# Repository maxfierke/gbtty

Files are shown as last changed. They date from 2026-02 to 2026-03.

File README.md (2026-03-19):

# gbtty

gbtty (pronounced: _gib-bit-EE_ / "gibbity") is a Game Boy (Color) hardware and
software project to turn the Game Boy into an ANSI-compatible terminal.

# Goals

The primary goal of this project is _funsies_. I wanted to work on a side
project where I could use Rust, play around with an RP2040, and do something
related to my current hyperfixation: the Game Boy.

Secondary goals include providing a useful-enough implementation of an ANSI
terminal, at least to be VT100-compatible to the extent that matters for modern
purposes.

Some stretch goals include supporting a broad set of ANSI escape codes, such as
text/background color on the Game Boy Color, some support for scrollback, and
perhaps even some support for some TUI elements depending on how wild I decide
to get with this.

## Anti-goals

I am not planning on turning this into an interactive terminal accepting input
to be passed back to the host. The only possible way to make this work would be
using some sort of on-screen keyboard control, and I am simply not masochistic
enough to use that.

# Current status

The software side of things is _mostly_ working for basic printing and support
for cursor movement, cursor reporting, and a few other CSI sequences. It's
currently setup to compile and run on the Waveshare RP2040-Zero and configured
to run on [this pico-gb-printer board](https://github.com/Raphael-Boichot/Collection-of-PCB-for-Game-Boy-Printer-Emulators/tree/main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)
as I happened to have a couple of these, but should be configurable to run on
other similar boards by remapping the GPIOs & swapping the BSP crate.

The hardware is still a work in-progress. The `pcb/` has a few different v1.0
designs that still need to be tested. The design is more-or-less the same as
other USB-to-link-cable boards out there, but I'm eventually trying to get it as
close as I can to the footprint of a USB-to-UART adapter.

# License

The firmware of the link adapter (contents of the root & `src/` directory) is
licensed under either the [Apache License Version 2.0](LICENSE-APACHE-2-0) or
[The MIT License](LICENSE-MIT)

The PCB (contents of `pcb/`) is licensed under
[Creative Commons Attribution-NonCommercial-ShareAlike 4.0 International](https://creativecommons.org/licenses/by-nc-sa/4.0/). **Commercial uses are strictly prohibited.**

The terminal emulator ROM itself (contents of the `gb/` directory) is derived
from orangeglo's Better Button Test, which is licensed under the [GNU General
Public License Version 3](gb/LICENSE), so the same license applies.

# Disclaimer

Game Boy™ is a trademark of Nintendo of America Inc.

# Useful resources

- [How Terminals Work](https://how-terminals-work.vercel.app/) - Interactive look at how ANSI terminals function (VT100 and xterm derivatives especially)
- [vt100.net/emu/](https://vt100.net/emu/) - Paul Flo Williams' tome on terminal emulation
- [Everything you never wanted to know about ANSI escape codes](https://notes.burke.libbey.me/ansi-escape-codes/)

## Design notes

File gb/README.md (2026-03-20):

# gbtty - GB client

This is the GB client application which actually runs on the Game Boy and does
the emulating of the VT100 by interpretting input delivered over the link port.

It's primarily a consumer, but does support some limited responses back to the
host, including cursor reporting, device attributes, as well as ACK and SYN IDLE.

## License

As mentioned in the [top-level README](../README.md) for the project, the GB client is licensed
under the terms of the GNU General Public License Version 3.

It uses elements of other projects licensed under the GNU General Public License
Version 3 or compatible licenses, including:

- [Better Button Test](https://github.com/orangeglo/better-button-test) by orangelo - original foundation of `src/main.c`, `src/palettes.h`
- [Portfolio 6x8](https://int10h.org/oldschool-pc-fonts/fontlist/font?portfolio_6x8) - bitmap font, based on FON version from [VileR](https://int10h.org/oldschool-pc-fonts/). Originally licensed under CC-BY-SA 4.0. I converted it to 8x8 1bpp tiles, which are a derivative work licensed under GNU General Public License Version 3.

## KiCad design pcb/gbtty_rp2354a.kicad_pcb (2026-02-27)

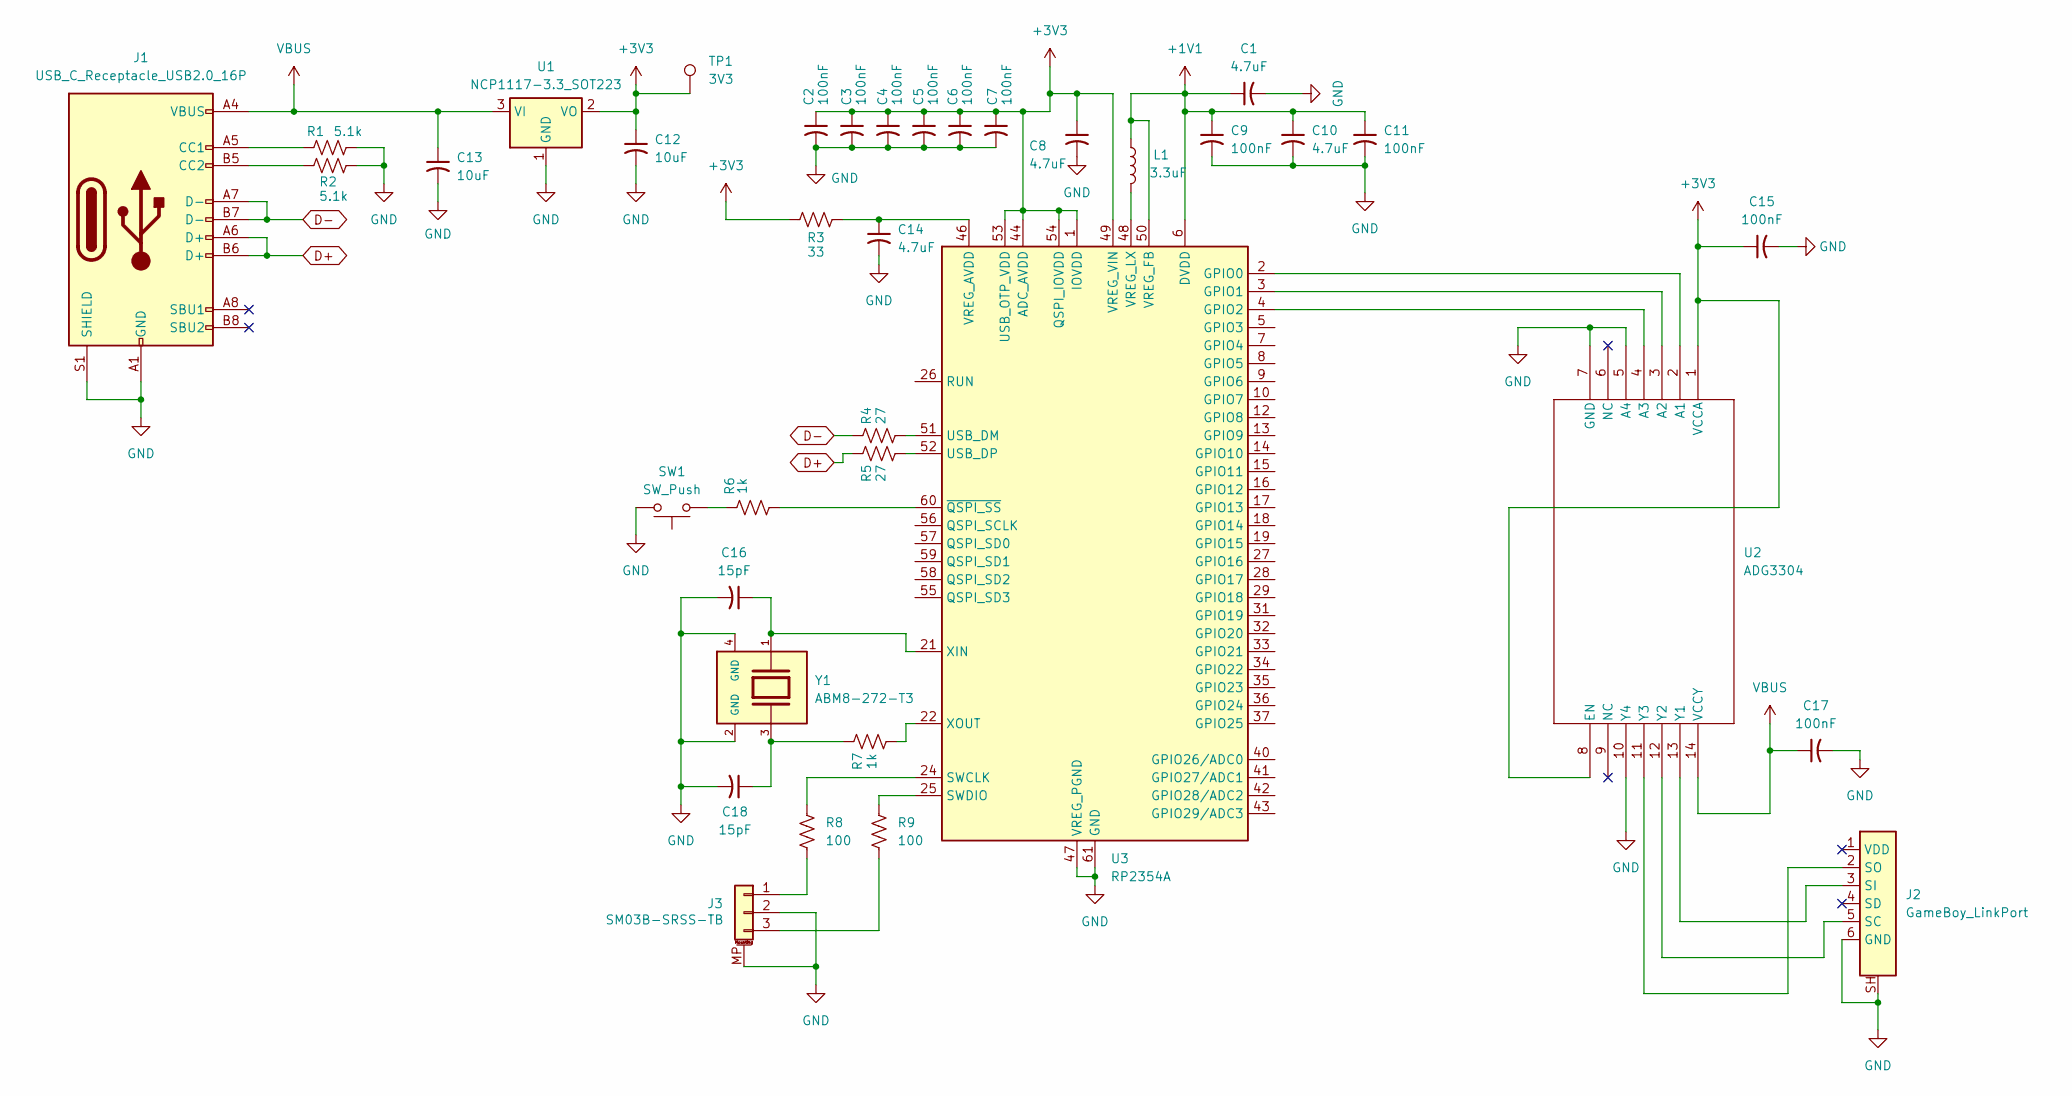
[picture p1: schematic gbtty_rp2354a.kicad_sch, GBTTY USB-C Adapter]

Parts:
C1, C8, C10, C14: 4.7uF; C_0603_1608Metric_Pad1.08x0.95mm_HandSolder
C2, C3, C4, C5, C6, C7, C9, C11, C15, C17: 100nF; C_0603_1608Metric_Pad1.08x0.95mm_HandSolder
C12, C13: 10uF; C_0603_1608Metric_Pad1.08x0.95mm_HandSolder
C16, C18: 15pF; C_0603_1608Metric_Pad1.08x0.95mm_HandSolder
J1: USB_C_Receptacle_USB2.0_16P; USB_C_Receptacle_GCT_USB4105-xx-A_16P_TopMnt_Horizontal
J2: GameBoy_LinkPort; GameBoy_LinkPort_MGB_Horizontal
J3: SM03B-SRSS-TB; JST_SH_BM03B-SRSS-TB_1x03-1MP_P1.00mm_Vertical
L1: 3.3uF; L_pol_2016
R1, R2: 5.1k; R_0603_1608Metric_Pad0.98x0.95mm_HandSolder
R3: 33; R_0603_1608Metric_Pad0.98x0.95mm_HandSolder
R4, R5: 27; R_0603_1608Metric_Pad0.98x0.95mm_HandSolder
R6, R7: 1k; R_0603_1608Metric_Pad0.98x0.95mm_HandSolder
R8, R9: 100; R_0603_1608Metric_Pad0.98x0.95mm_HandSolder
SW1: SW_Push; SW_SPST_TL3305A
TP1: 3V3; TestPoint_Pad_D1.0mm
U1: NCP1117-3.3_SOT223; SOT-223-3_TabPin2
U2: ADG3304; RU_14_ADI
U3: RP2354A; QFN-60-1EP_7x7mm_P0.4mm_EP3.4x3.4mm
Y1: ABM8-272-T3; XTAL_ABM8-272-T3; PARTREV 07-29-20

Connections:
+1V1: C1.1, C9.1, C10.1, C11.1, L1.1, U3.6 (DVDD), U3.23 (DVDD), U3.39 (DVDD), U3.50 (VREG_FB)
+3V3: C2.1, C3.1, C4.1, C5.1, C6.1, C7.1, C8.1, C12.1, C15.1, R3.2, TP1.1, U1.2 (VO), U2.1 (VCCA), U2.8 (EN), U3.1 (IOVDD), U3.11 (IOVDD), U3.20 (IOVDD), U3.30 (IOVDD), U3.38 (IOVDD), U3.44 (ADC_AVDD), U3.45 (IOVDD), U3.49 (VREG_VIN), U3.53 (USB_OTP_VDD), U3.54 (QSPI_IOVDD)
D+: J1.A6 (D+), J1.B6 (D+), R5.1
D-: J1.A7 (D-), J1.B7 (D-), R4.1
GND: C1.2, C2.2, C3.2, C4.2, C5.2, C6.2, C7.2, C8.2, C9.2, C10.2, C11.2, C12.2, C13.2, C14.2, C15.2, C16.2, C17.2, C18.2, J1.A1 (GND), J1.A12 (GND), J1.B1 (GND), J1.B12 (GND), J1.S1 (SHIELD), J2.6 (GND), J2.SH, J3.2, J3.MP (MountPin), R1.2, R2.2, SW1.2, U1.1 (GND), U2.5 (A4), U2.7 (GND), U2.10 (Y4), U3.47 (VREG_PGND), U3.61 (GND), Y1.2 (GND), Y1.4 (GND)
unnamed: C18.1, R7.1, Y1.3
unnamed: J1.A5 (CC1), R1.1
unnamed: J1.B5 (CC2), R2.1
unnamed: J2.5 (SC), U2.12 (Y2)
unnamed: J2.3 (SI), U2.13 (Y1)
unnamed: J2.2 (SO), U2.11 (Y3)
unnamed: J3.1, R8.2
unnamed: J3.3, R9.2
unnamed: R6.1, SW1.1
unnamed: U2.2 (A1), U3.2 (GPIO0)
unnamed: U2.3 (A2), U3.3 (GPIO1)
unnamed: U2.4 (A3), U3.4 (GPIO2)
unnamed: R8.1, U3.24 (SWCLK)
unnamed: R9.1, U3.25 (SWDIO)
unnamed: R4.2, U3.51 (USB_DM)
unnamed: R5.2, U3.52 (USB_DP)
unnamed: C14.1, R3.1, U3.46 (VREG_AVDD)
unnamed: L1.2, U3.48 (VREG_LX)
unnamed: C16.1, U3.21 (XIN), Y1.1
unnamed: R7.2, U3.22 (XOUT)
unnamed: R6.2, U3.60 (~QSPI_SS)
VBUS: C13.1, C17.1, J1.A4 (VBUS), J1.A9 (VBUS), J1.B4 (VBUS), J1.B9 (VBUS), U1.3 (VI), U2.14 (VCCY)

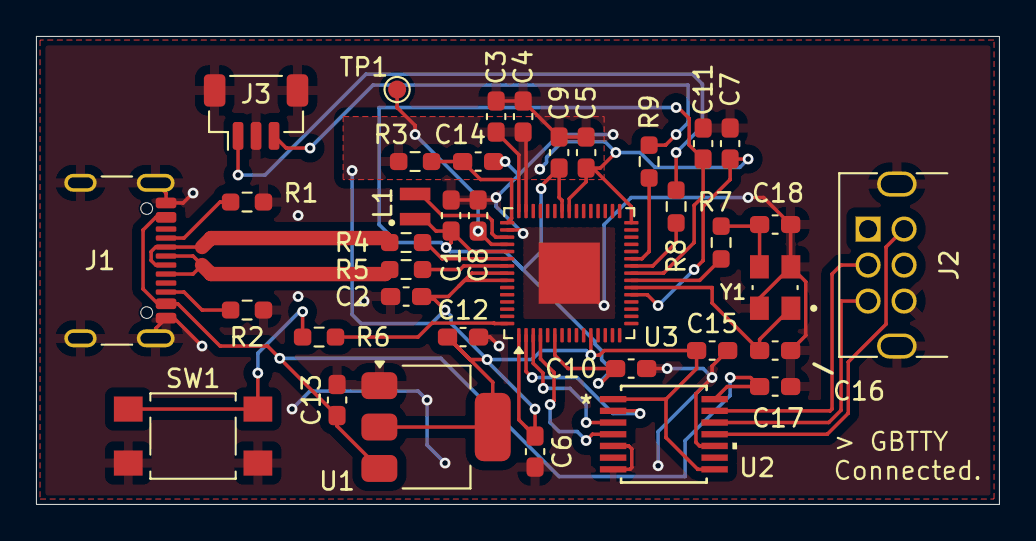
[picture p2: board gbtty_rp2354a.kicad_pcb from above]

Board: 2 copper layers, 53.5 x 26.0 mm, 37 parts (0 on the bottom side), 27 nets.

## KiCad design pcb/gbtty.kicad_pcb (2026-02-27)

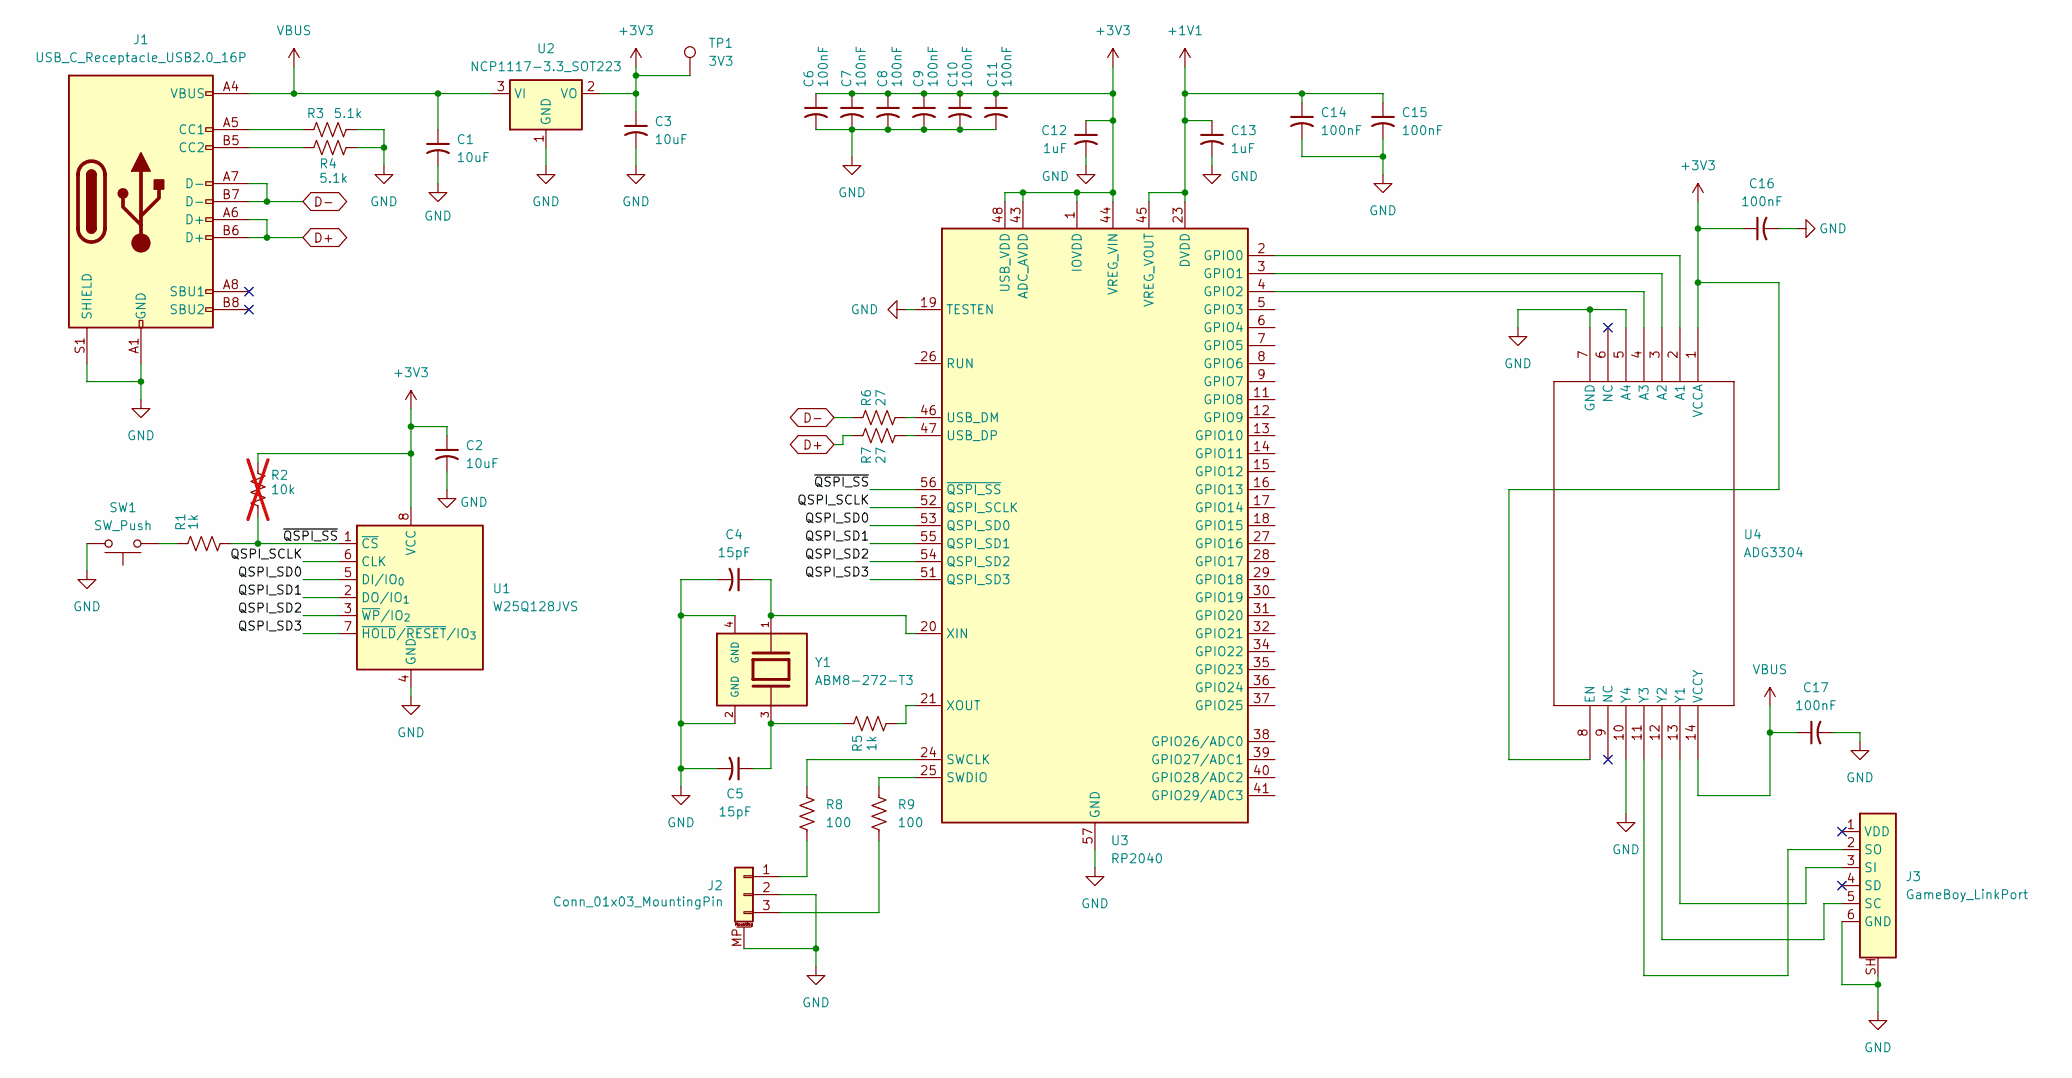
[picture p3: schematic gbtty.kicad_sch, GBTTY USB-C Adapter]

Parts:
C1, C2, C3: 10uF; C_0603_1608Metric_Pad1.08x0.95mm_HandSolder
C4, C5: 15pF; C_0603_1608Metric_Pad1.08x0.95mm_HandSolder
C6, C7, C8, C9, C10, C11, C14, C15, C16, C17: 100nF; C_0603_1608Metric_Pad1.08x0.95mm_HandSolder
C12, C13: 1uF; C_0603_1608Metric_Pad1.08x0.95mm_HandSolder
J1: USB_C_Receptacle_USB2.0_16P; USB_C_Receptacle_GCT_USB4105-xx-A_16P_TopMnt_Horizontal
J2: Conn_01x03_MountingPin; JST_SH_BM03B-SRSS-TB_1x03-1MP_P1.00mm_Vertical
J3: GameBoy_LinkPort; GameBoy_LinkPort_MGB_Horizontal
R1, R5: 1k; R_0603_1608Metric_Pad0.98x0.95mm_HandSolder
R2: 10k; R_0603_1608Metric_Pad0.98x0.95mm_HandSolder; not fitted
R3, R4: 5.1k; R_0603_1608Metric_Pad0.98x0.95mm_HandSolder
R6, R7: 27; R_0603_1608Metric_Pad0.98x0.95mm_HandSolder
R8, R9: 100; R_0603_1608Metric_Pad0.98x0.95mm_HandSolder
SW1: SW_Push; SW_SPST_TL3305A
TP1: 3V3; TestPoint_Pad_D1.0mm
U1: W25Q128JVS; SOIC-8_5.3x5.3mm_P1.27mm
U2: NCP1117-3.3_SOT223; SOT-223-3_TabPin2
U3: RP2040; QFN-56-1EP_7x7mm_P0.4mm_EP3.2x3.2mm
U4: ADG3304; RU_14_ADI
Y1: ABM8-272-T3; XTAL_ABM8-272-T3; PARTREV 07-29-20

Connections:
+1V1: C13.1, C14.1, C15.1, U3.23 (DVDD), U3.45 (VREG_VOUT), U3.50 (DVDD)
+3V3: C2.1, C3.1, C6.1, C7.1, C8.1, C9.1, C10.1, C11.1, C12.1, C16.1, R2.1, TP1.1, U1.8 (VCC), U2.2 (VO), U3.1 (IOVDD), U3.10 (IOVDD), U3.22 (IOVDD), U3.33 (IOVDD), U3.42 (IOVDD), U3.43 (ADC_AVDD), U3.44 (VREG_VIN), U3.48 (USB_VDD), U3.49 (IOVDD), U4.1 (VCCA), U4.8 (EN)
/QSPI_SCLK: U1.6 (CLK), U3.52 (QSPI_SCLK)
/QSPI_SD0: U1.5 (DI/IO_{0}), U3.53 (QSPI_SD0)
/QSPI_SD1: U1.2 (DO/IO_{1}), U3.55 (QSPI_SD1)
/QSPI_SD2: U1.3 (~WP/IO_{2}), U3.54 (QSPI_SD2)
/QSPI_SD3: U1.7 (~HOLD/~RESET/IO_{3}), U3.51 (QSPI_SD3)
/~QSPI_SS: R1.2, R2.2, U1.1 (~CS), U3.56 (~QSPI_SS)
D+: J1.A6 (D+), J1.B6 (D+), R7.1
D-: J1.A7 (D-), J1.B7 (D-), R6.1
GND: C1.2, C2.2, C3.2, C4.2, C5.2, C6.2, C7.2, C8.2, C9.2, C10.2, C11.2, C12.2, C13.2, C14.2, C15.2, C16.2, C17.2, J1.A1 (GND), J1.A12 (GND), J1.B1 (GND), J1.B12 (GND), J1.S1 (SHIELD), J2.2, J2.MP (MountPin), J3.6 (GND), J3.SH, R3.2, R4.2, SW1.2, U1.4 (GND), U2.1 (GND), U3.19 (TESTEN), U3.57 (GND), U4.5 (A4), U4.7 (GND), U4.10 (Y4), Y1.2 (GND), Y1.4 (GND)
unnamed: C5.1, R5.1, Y1.3
unnamed: J1.A5 (CC1), R3.1
unnamed: J1.B5 (CC2), R4.1
unnamed: J2.1, R8.2
unnamed: J2.3, R9.2
unnamed: J3.5 (SC), U4.12 (Y2)
unnamed: J3.3 (SI), U4.13 (Y1)
unnamed: J3.2 (SO), U4.11 (Y3)
unnamed: R1.1, SW1.1
unnamed: U3.2 (GPIO0), U4.2 (A1)
unnamed: U3.3 (GPIO1), U4.3 (A2)
unnamed: U3.4 (GPIO2), U4.4 (A3)
unnamed: R8.1, U3.24 (SWCLK)
unnamed: R9.1, U3.25 (SWDIO)
unnamed: R6.2, U3.46 (USB_DM)
unnamed: R7.2, U3.47 (USB_DP)
unnamed: C4.1, U3.20 (XIN), Y1.1
unnamed: R5.2, U3.21 (XOUT)
VBUS: C1.1, C17.1, J1.A4 (VBUS), J1.A9 (VBUS), J1.B4 (VBUS), J1.B9 (VBUS), U2.3 (VI), U4.14 (VCCY)

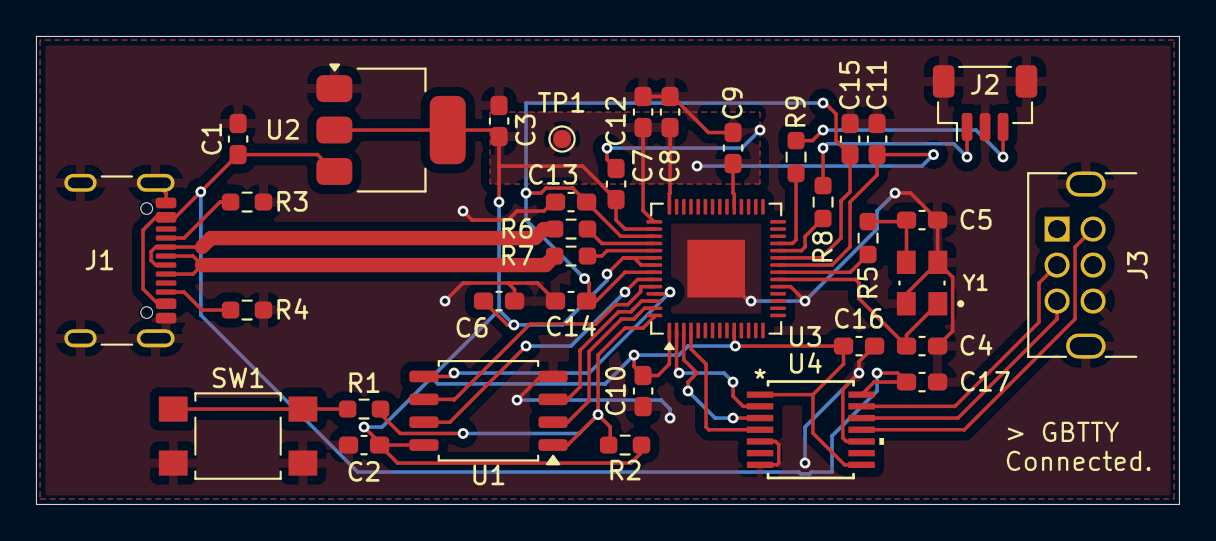
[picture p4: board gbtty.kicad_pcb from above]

Board: 2 copper layers, 63.5 x 26.0 mm, 36 parts (0 on the bottom side), 30 nets.

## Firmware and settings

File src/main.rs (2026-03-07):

//! Runs a Serial TTY to GB link translation
//!
//! This allows a GB to act as an ANSI terminal (assuming software support on
//! the GB side)
#![no_std]
#![no_main]
#![allow(static_mut_refs)]

use bsp::entry;
use defmt::*;
use defmt_rtt as _;
use rp2040_panic_usb_boot as _;

use heapless::spsc::{Producer, Queue};
use usb_device::{
    bus::UsbBusAllocator,
    device::{StringDescriptors, UsbDevice, UsbDeviceBuilder, UsbVidPid},
};
use usbd_serial::{
    embedded_io::{Read, Write},
    SerialPort,
};

#[cfg(feature = "rp-pico")]
pub use rp_pico as bsp;

#[cfg(feature = "waveshare-rp2040-zero")]
pub use waveshare_rp2040_zero as bsp;

use bsp::hal::{
    clocks::{init_clocks_and_plls, Clock},
    fugit,
    gpio::{FunctionPio0, Pin},
    pac::{self, interrupt, Interrupt},
    pio,
    sio::Sio,
    usb::UsbBus,
    watchdog::Watchdog,
};

mod link_port;

/// The USB Device Driver (shared with the interrupt).
static mut USB_DEVICE: Option<UsbDevice<bsp::hal::usb::UsbBus>> = None;

/// The USB Bus Driver (shared with the interrupt).
static mut USB_BUS: Option<UsbBusAllocator<bsp::hal::usb::UsbBus>> = None;

/// The USB Serial Device Driver (shared with the interrupt).
static mut USB_SERIAL: Option<SerialPort<bsp::hal::usb::UsbBus>> = None;

/// Link port TX queue writer
static mut LINK_PORT_BUFFER_WRITER: Option<Producer<'_, u8>> = None;

const LINK_PORT_CLOCK_HZ: u32 = 262144; // ~32KB/s on normal speed

const LINK_PORT_ACK: u8 = 0x6;

const LINK_PORT_SYN_IDLE: u8 = 0x16;

#[entry]
fn main() -> ! {
    let mut pac = pac::Peripherals::take().unwrap();
    let mut watchdog = Watchdog::new(pac.WATCHDOG);
    let sio = Sio::new(pac.SIO);

    let clocks = init_clocks_and_plls(
        bsp::XOSC_CRYSTAL_FREQ,
        pac.XOSC,
        pac.CLOCKS,
        pac.PLL_SYS,
        pac.PLL_USB,
        &mut pac.RESETS,
        &mut watchdog,
    )
    .ok()
    .unwrap();

    let clock_cycles_per_ms = clocks.system_clock.freq().to_Hz() / 1000;

    let pins = bsp::Pins::new(
        pac.IO_BANK0,
        pac.PADS_BANK0,
        sio.gpio_bank0,
        &mut pac.RESETS,
    );

    #[cfg(feature = "rp-pico")]
    let (sin_pin, sck_pin, sout_pin) = {
        let gp0: Pin<_, FunctionPio0, _> = pins.gp0.into_function();
        let gp1: Pin<_, FunctionPio0, _> = pins.gp1.into_function();
        let gp2: Pin<_, FunctionPio0, _> = pins.gp2.into_function();
        (gp0, gp1, gp2)
    };

    #[cfg(feature = "waveshare-rp2040-zero")]
    let (sin_pin, sck_pin, sout_pin) = {
        let gp0: Pin<_, FunctionPio0, _> = pins.gp0.into_function();
        let gp2: Pin<_, FunctionPio0, _> = pins.gp2.into_function();
        let gp3: Pin<_, FunctionPio0, _> = pins.gp3.into_function();
        (gp0, gp2, gp3)
    };

    let (mut pio0, sm0, _sm1, _sm2, _sm3) = pio::PIOExt::split(pac.PIO0, &mut pac.RESETS);
    let mut leader_program = link_port::install_link_port_leader_program(&mut pio0)
        .ok()
        .unwrap();

    let port = link_port::PioGbLinkPortLeader::new(
        sin_pin.reconfigure(),
        sck_pin.reconfigure(),
        sout_pin.reconfigure(),
        sm0,
        &mut leader_program,
        fugit::HertzU32::Hz(LINK_PORT_CLOCK_HZ).convert(),
        clocks.system_clock.freq(),
    );

    let usb_bus = UsbBusAllocator::new(UsbBus::new(
        pac.USBCTRL_REGS,
        pac.USBCTRL_DPRAM,
        clocks.usb_clock,
        true,
        &mut pac.RESETS,
    ));
    unsafe {
        // SAFETY: This is safe as interrupts haven't been started yet
        USB_BUS = Some(usb_bus);
    }

    // Grab a reference to the USB Bus allocator. We are promising to the
    // compiler not to take mutable access to this global variable whilst this
    // reference exists!
    let bus_ref = unsafe { USB_BUS.as_ref().unwrap() };

    let serial = SerialPort::new(bus_ref);
    unsafe {
        USB_SERIAL = Some(serial);
    }

    let mut usb_dev = UsbDeviceBuilder::new(bus_ref, UsbVidPid(0x2E8A, 0x000A))
        .strings(&[StringDescriptors::default()
            .manufacturer("GBTTY")
            .product("Serial port that outputs to Game Boy link port")
            .serial_number("TEST")])
        .unwrap()
        .device_class(2) // from: https://www.usb.org/defined-class-codes
        .build();
    let _ = usb_dev.force_reset();
    unsafe {
        // SAFETY: This is safe as interrupts haven't been started yet
        USB_DEVICE = Some(usb_dev);
    }

    let mut link_port_queue_reader = {
        let (p, c) = {
            static mut LINK_PORT_BUFFER_QUEUE: Queue<u8, 4096> = Queue::new();
            // SAFETY: `LINK_PORT_BUFFER_QUEUE` is only accessible in this scope
            // and `main` is only called once.
            #[allow(static_mut_refs)]
            unsafe {
                LINK_PORT_BUFFER_QUEUE.split()
            }
        };

        unsafe {
            LINK_PORT_BUFFER_WRITER = Some(p);
        };

        c
    };

    // Enable the USB interrupt
    unsafe {
        pac::NVIC::unmask(Interrupt::USBCTRL_IRQ);
    };

    let mut active_link_port = port.enable();

    loop {
        match link_port_queue_reader.peek() {
            None => {
                let _ = active_link_port.flush();
                let idle = [LINK_PORT_SYN_IDLE];
                match active_link_port.write(&idle) {
                    Ok(_) => {
                        let mut resp = [0u8];
                        match active_link_port.read(&mut resp) {
                            Ok(1) => match resp[0] {
                                LINK_PORT_SYN_IDLE | LINK_PORT_ACK | 0x00 | 0xFF => {
                                    // Let's both twiddle our thumbs in silence
                                }
                                _ => {
                                    // SAFETY: While not totally safe, we're only writing from
                                    // here and reading in the interrupt. R/W buffers are seperate.
                                    // USB Bus is mutexed. It's fine for now :shruggie:
                                    let serial = unsafe { USB_SERIAL.as_mut().unwrap() };
                                    if serial.write(&resp).is_err() {
                                        error!("unable to enqueue to serial port");
                                    }
                                }
                            },
                            Ok(_) => {}
                            Err(_) => error!("pio error reading from link port"),
                        }
                    }
                    Err(_err) => error!("unable to write SYN_IDLE to link port"),
                }
            }
            Some(ch) => {
                let buf = [*ch];
                match active_link_port.write(&buf) {
                    Ok(_) => {
                        let _ = link_port_queue_reader.dequeue();

                        let mut resp = [0u8];
                        match active_link_port.read(&mut resp) {
                            Ok(1) => {
                                match resp[0] {
                                    LINK_PORT_SYN_IDLE | LINK_PORT_ACK | 0x00 | 0xFF => {
                                        // Let's both twiddle our thumbs in silence
                                    }
                                    _ => {
                                        // SAFETY: While not totally safe, we're only writing from
                                        // here and reading in the interrupt. R/W buffers are seperate.
                                        // USB Bus is mutexed. It's fine for now :shruggie:
                                        let serial = unsafe { USB_SERIAL.as_mut().unwrap() };
                                        if serial.write(&resp).is_err() {
                                            error!("unable to enqueue to serial port");
                                        }
                                    }
                                }
                            }
                            Ok(_) => {}
                            Err(_) => error!("pio error reading from link port"),
                        }
                    }
                    Err(_err) => error!("unable to write byte from queue to link port"),
                }
            }
        }

        cortex_m::asm::delay(clock_cycles_per_ms);
    }
}

/// This function is called whenever the USB Hardware generates an Interrupt
/// Request.
///
/// We do all our USB work under interrupt, so the main thread can continue on
/// knowing nothing about USB.
#[allow(non_snake_case)]
#[interrupt]
fn USBCTRL_IRQ() {
    // SAFETY: These are safe to access because they're only accessed here
    // during an interrupt and are always set before enabling this interrupt
    let usb_dev = unsafe { USB_DEVICE.as_mut().unwrap() };
    let serial = unsafe { USB_SERIAL.as_mut().unwrap() };
    let link_port_queue = unsafe { LINK_PORT_BUFFER_WRITER.as_mut().unwrap() };

    if usb_dev.poll(&mut [serial]) {
        let mut buf = [0u8; 128];
        match serial.read(&mut buf) {
            Err(_e) => error!("usb error reading from serial port"),
            Ok(0) => {}
            Ok(count) => {
                for byte in &buf[..count] {
                    if link_port_queue.enqueue(*byte).is_err() {
                        error!("unable to write byte to link port queue");
                    }
                }
            }
        }
    }
}

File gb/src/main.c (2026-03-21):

#include <gb/cgb.h>
#include <gb/crash_handler.h>
#include <gb/gb.h>
#include <stdint.h>
#include <stdio.h>
#include <stdlib.h>
#include <string.h>

#include "link.h"
#include "palettes.h"
#include "portfolio.h"
#include "term.h"

// Keys
uint8_t previous_keys = 0;
uint8_t keys = 0;
#define UPDATE_KEYS()   \
  previous_keys = keys; \
  keys = joypad()
#define KEY_PRESSED(K) (keys & (K))
#define KEY_TICKED(K) ((keys & (K)) && !(previous_keys & (K)))
#define KEY_RELEASED(K) (!(keys & (K)) && (previous_keys & (K)))
#define NO_KEYS_PRESSED() keys == 0

#define SPRITE_DMG_CURSOR 0

#define PORTFOLIO_FIRST_TILE 0

// Globals
uint8_t cursor_tile[] = {0, 0, 0, 0, 0, 0, 0, 0, 0, 0, 0, 0, 0, 0, 0, 0};
char line_buffer[20];

void setup_fonts(void) {
  set_1bpp_colors(1, 2);
  set_bkg_1bpp_data(PORTFOLIO_FIRST_TILE, portfolio_TILE_COUNT,
                    portfolio_tiles);
}

void print_char_at(char ch, uint8_t x, uint8_t y, term_sgr_mode_t mode) {
  set_bkg_tile_xy(x, y, PORTFOLIO_FIRST_TILE + (uint8_t)ch);

  if (DEVICE_SUPPORTS_COLOR) {
    if (mode == TERM_SGR_INVERSE) {
      set_bkg_attribute_xy(x, y, 1);
    } else {
      set_bkg_attribute_xy(x, y, 0);
    }
  } else {
    // TODO: Determine how to support invert on DMG/GBP
  }
}

void print_str_at(char str[], uint8_t x, uint8_t y, term_sgr_mode_t mode) {
  uint8_t i = 0;

  while (str[i] != '\0') {
    if (x + i > TERM_MAX_X) break;
    print_char_at(str[i], x + i, y, mode);
    i++;
  }
}

void draw_term_state(term_t* term) {
  if (!term->esc && !term->csi) {
    print_str_at("   ", 1, 16, TERM_SGR_DEFAULT);
  } else if (term->esc && !term->csi) {
    print_str_at("ESC", 1, 16, TERM_SGR_INVERSE);
  } else if (term->csi && !term->csi_state->args[0]) {
    print_str_at("CSI", 1, 16, TERM_SGR_INVERSE);
  } else if (term->csi) {
    sprintf(line_buffer, "^[[%s", (unsigned char*)term->csi_state->arg_buffer);
    print_str_at(line_buffer, 1, 16, TERM_SGR_INVERSE);
  }

  uint8_t buffer_head = link_rx_buffer_head;

  sprintf(
      line_buffer, "%hx %hx %hx %hx",
      (uint8_t)link_rx_buffer[(uint8_t)(buffer_head - 4) % LINK_RX_BUFFER_SIZE],
      (uint8_t)link_rx_buffer[(uint8_t)(buffer_head - 3) % LINK_RX_BUFFER_SIZE],
      (uint8_t)link_rx_buffer[(uint8_t)(buffer_head - 2) % LINK_RX_BUFFER_SIZE],
      (uint8_t)
          link_rx_buffer[(uint8_t)(buffer_head - 1) % LINK_RX_BUFFER_SIZE]);
  print_str_at(line_buffer, 8, 16, TERM_SGR_INVERSE);
}

// Main Loop
void draw(term_t* term) {
  if (!term->started) {
    print_str_at("GBTTY", 8, 1, TERM_SGR_DEFAULT);
    print_str_at("START to begin", 3, 12, TERM_SGR_INVERSE);
  } else {
    for (uint8_t row = TERM_MIN_Y; row <= TERM_MAX_Y; row++) {
      for (uint8_t col = TERM_MIN_X; col <= TERM_MAX_X; col++) {
        if ((row == term->y && col == term->x) || term->cells[row][col].mode) {
          print_char_at(term->cells[row][col].ch, col, row, TERM_SGR_INVERSE);
        } else {
          print_char_at(term->cells[row][col].ch, col, row, TERM_SGR_DEFAULT);
        }
      }
    }

    if (!DEVICE_SUPPORTS_COLOR) {
      set_sprite_1bpp_data(0, 1, cursor_tile);
      move_sprite(SPRITE_DMG_CURSOR, (term->x * 8) + 8, (term->y * 8) + 16);
    }
  }

  draw_term_state(term);
}

void update(term_t* term) {
  if (!term->started) {
    if (KEY_RELEASED(J_START)) {
      term->started = 1;
      link_port_init();
    }

    return;
  }

  if (KEY_PRESSED(J_SELECT) && KEY_PRESSED(J_START)) {
    term_clear_screen(term);
  }

  if (KEY_PRESSED(J_UP)) {
    term_cursor_up(term);
  } else if (KEY_PRESSED(J_DOWN)) {
    term_cursor_down(term);
  }

  if (KEY_PRESSED(J_LEFT)) {
    term_cursor_backward(term);
  } else if (KEY_PRESSED(J_RIGHT)) {
    term_cursor_forward(term);
  }

  if (term->started) {
    while (link_rx_buffer_head != link_rx_buffer_tail) {
      unsigned char next_char = link_rx_buffer[link_rx_buffer_tail];
      link_rx_buffer_tail = (link_rx_buffer_tail + 1) % LINK_RX_BUFFER_SIZE;
      term_handle_link_byte(term, next_char);
    }
  }
}

void main(void) {
  DISPLAY_OFF;

  ENABLE_RAM;
  SHOW_BKG;
  SHOW_SPRITES;
  SPRITES_8x8;

  if (DEVICE_SUPPORTS_COLOR) {
    set_bkg_palette(0, 1, palettePurple);
    set_bkg_palette(1, 1, paletteInvertPurple);
  } else {
    BGP_REG = DMG_PALETTE(DMG_BLACK, DMG_WHITE, DMG_BLACK, DMG_DARK_GRAY);
    OBP0_REG = DMG_PALETTE(DMG_WHITE, DMG_BLACK, DMG_WHITE, DMG_DARK_GRAY);
    hide_sprite(SPRITE_DMG_CURSOR);
  }

  setup_fonts();

  term_t term = {0};
  term_init(&term);

  DISPLAY_ON;

  while (1) {
    UPDATE_KEYS();

    update(&term);
    draw(&term);

    vsync();
  }
}

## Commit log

2025-12-26 gb: Import a very barebones GB rom based on better-button-test
2025-12-30 gb: barebones dumb terminal
    Not much supported. Basic ASCII set supported by the built-in GBDK IBM font. Unprintable characters skipped. Functioning newlines, backspace, and wrapping.
    [main.c]
2026-01-19 rp: fix multi-byte writes
    [main.rs]
2026-01-22 gb: increase link buffer size to 128 bytes
    This seems to help with avoiding overflow situations
    w/ programmatic output.
    [main.c]
2026-01-22 rp: drop PIO clock to ~262kHz for 32KB/s data rate
    While 500 kHz does work to some degree it is simply too fast
    for the GB to keep up with in normal-speed mode if the buffer
    is constantly full. Will revisit when exploring double-speed later
    [main.rs]
2026-02-27 pcb: Add initial pcb design
    [gbtty.kicad_pcb, gbtty.kicad_sch]
2026-02-27 pcb: Add alt RP2354A pcb design
    This also hasn't been validated yet either, and is probably more
    likely to need changes.
    [gbtty_rp2354a.kicad_pcb, gbtty_rp2354a.kicad_sch]
2026-02-27 pcb: Put the rp2354a design in the shrink-ray
    [gbtty_rp2354a.kicad_pcb, gbtty_rp2354a.kicad_sch]
2026-02-27 pcb: Update generated BOM pages
2026-02-27 rp: Customize pins for rp-pico
2026-02-27 Add current status to README
2026-02-27 rp: remove erroneous shift on link port read
    this was what I get for basing this off a UART implementation
2026-02-27 gb: implement cursor navigation with arrow keys, fix CSI arg parsing
    [main.c]
2026-03-09 Update current status in README
2026-03-12 gb: (mostly) move off gbdk font system
    Still using `font_load` and `font_color` to load fonts initially, but that's it.
    In addition, switched to using font_ibm_fixed, which seems to supported extended ASCII.
    Unfortunately, this leaves us with no room for other fonts, but that's okay.
2026-03-13 gb: add sprite based cursor for DMG/MGB
    This seems to be the easiest way to do an invert here -- not sure how we'll do this for terminal cells, but less concerned with that.
    [main.c]
2026-03-17 gb: fix inverse being improperly applied following refactor
    [main.c]
2026-03-19 gb: swap in oldschool-cga-8x8, a cp437 font
    This removes the last use of the gbdk font system.
    It's not my favorite font, so this is likely a stop gap for a bit,
    as its close to font_ibm_fixed
    [main.c]
2026-03-20 gb: replace oldschool-cga-8x8 with portfolio
    [main.c, portfolio.h]

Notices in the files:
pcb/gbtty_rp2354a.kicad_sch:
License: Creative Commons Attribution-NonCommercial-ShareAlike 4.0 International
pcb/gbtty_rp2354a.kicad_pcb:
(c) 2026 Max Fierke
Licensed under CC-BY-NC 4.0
